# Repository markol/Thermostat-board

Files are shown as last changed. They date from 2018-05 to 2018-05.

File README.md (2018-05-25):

## Thermostat board on AVR atmega MCU
Digital temperature controler. Powered from mains network, can be build into DIY hardware or appiliances like fridge or oven. Easy to at home make, non precsion requiring THT desin with numeric 7-segment LED display, 2 control buttons, buzzer and rotary encoder for temp adjustment. Temperature is measured by one or two thermistors, all processing is done by atmega8 microcontroller or similar. Look also [here](http://github.com/markol/Thermostat-firmware) for firmware for this board. 

Design is made with KiCad, remember to add project footprint libraries (from *custom_fp.pretty* directory) when opening first time.

Currently project has only one master branch, other may appear when development proceed.

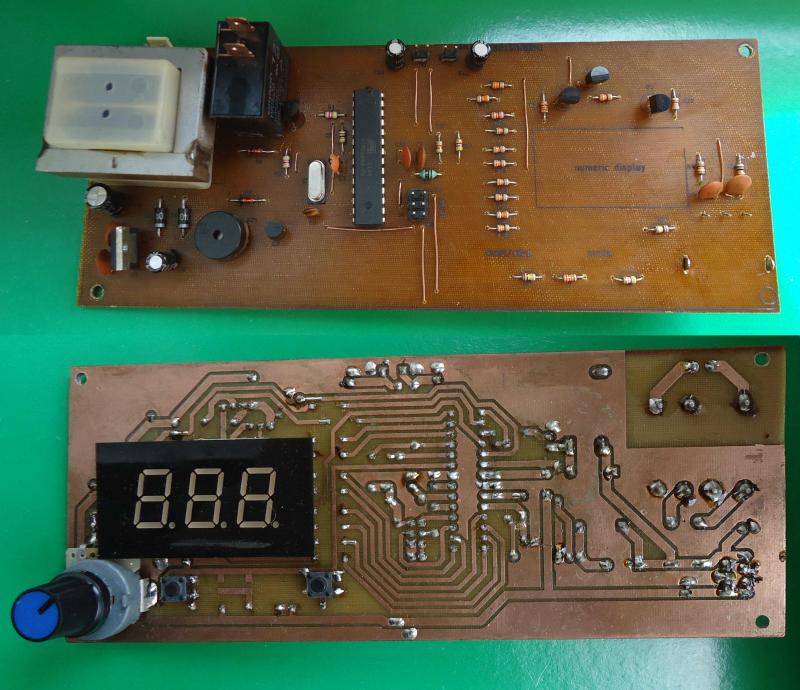
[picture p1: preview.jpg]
Prewiev


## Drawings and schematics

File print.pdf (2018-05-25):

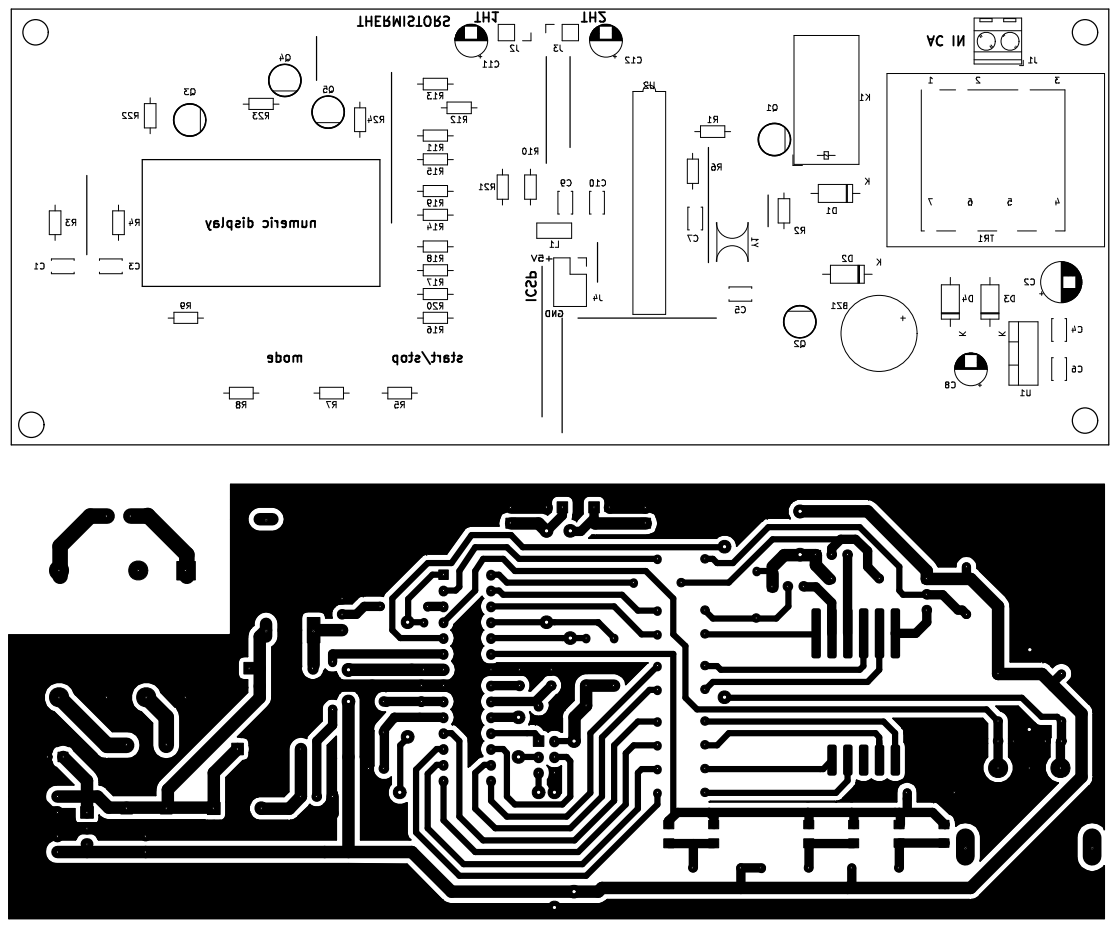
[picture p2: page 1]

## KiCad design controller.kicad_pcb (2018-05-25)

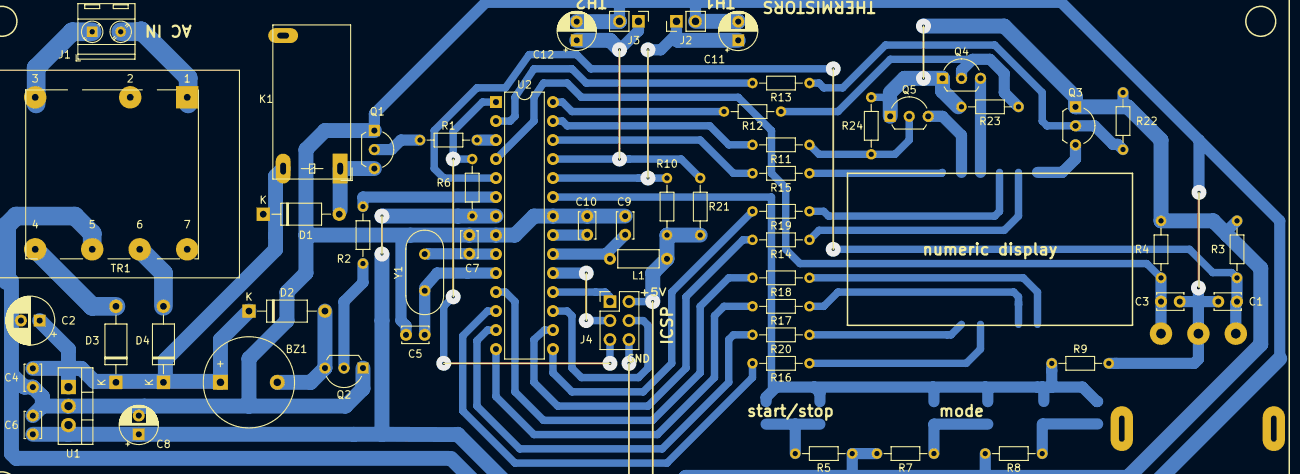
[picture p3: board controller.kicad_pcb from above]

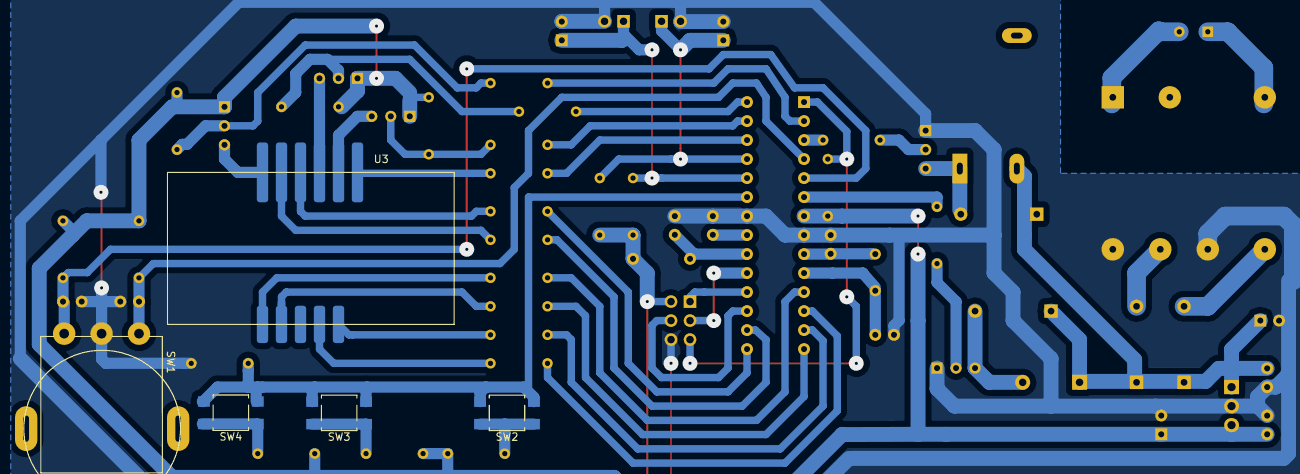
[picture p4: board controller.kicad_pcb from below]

Board: 2 copper layers, 61 parts (5 on the bottom side), 52 nets.

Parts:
BZ1: Buzzer; Buzzer_12x9.5RM7.6
C1, C3, C4, C6, C9, C10: 100nF; C_Disc_D3.4mm_W2.1mm_P2.50mm
C2: 100uF; CP_Radial_D6.3mm_P2.50mm
C5, C7: 22pF; C_Disc_D3.4mm_W2.1mm_P2.50mm
C8, C11, C12: 10uF; CP_Radial_D5.0mm_P2.50mm
D1, D2, D3, D4: D; D_A-405_P10.16mm_Horizontal
J1: AC_PWR; TerminalBlock_MetzConnect_Type086_RT03402HBLC_1x02_P3.81mm_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
J2: THERMISTOR1; PinHeader_1x02_P2.54mm_Vertical
J3: THERMISTOR2; PinHeader_1x02_P2.54mm_Vertical
J4: AVR_ICSP; PinHeader_2x03_P2.54mm_Vertical
K1: FRT5_separated; Relay_Omron
L1: L; L_Axial_L5.3mm_D2.2mm_P7.62mm_Horizontal_Vishay_IM-1
Q1, Q2: S9013; TO-92L_Inline_Wide
Q3, Q4, Q5: S9015; TO-92L_Inline_Wide
R1, R2: 4k7; R_Axial_DIN0204_L3.6mm_D1.6mm_P7.62mm_Horizontal
R3, R4, R5, R6: 10k; R_Axial_DIN0204_L3.6mm_D1.6mm_P7.62mm_Horizontal
R7: 22k; R_Axial_DIN0204_L3.6mm_D1.6mm_P7.62mm_Horizontal
R8: 47k; R_Axial_DIN0204_L3.6mm_D1.6mm_P7.62mm_Horizontal
R9: 100k; R_Axial_DIN0204_L3.6mm_D1.6mm_P7.62mm_Horizontal
R10, R21: 4.7k; R_Axial_DIN0204_L3.6mm_D1.6mm_P7.62mm_Horizontal
R11, R12, R13, R22, R23, R24: 3k3; R_Axial_DIN0204_L3.6mm_D1.6mm_P7.62mm_Horizontal
R14, R15, R16, R17, R18, R19, R20: 330; R_Axial_DIN0204_L3.6mm_D1.6mm_P7.62mm_Horizontal
SW1: Rotary_Encoder; Encoder_Vertical
SW2: START/STOP; SW_SPST_TL3305A
SW3: MODE; SW_SPST_TL3305A
SW4: SW_Push; SW_SPST_TL3305A
TR1: dmr-63; Transformer_7pin
U1: L7805; TO-220-3_Vertical
U2: ATmega8L-8PU; DIP-28_W7.62mm
U3: 3digit11pin
Y1: Crystal; Crystal_HC18-U_Vertical

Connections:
+5V: C6.1, C8.1, J4.2, L1.1, Q3.1, Q4.1, Q5.1, R3.2, R4.2, R5.2, R6.1, R7.2, R8.2, R10.1, R21.1, R22.2, R23.2, R24.2, U1.3, U2.7
/BUZZER: R2.2, U2.6
/DIGIT1: R13.2, U2.2
/DIGIT2: R12.2, U2.28
/DIGIT3: R11.2, U2.27
/DIGIT_A: R14.2, U2.16
/DIGIT_B: R15.2, U2.26
/DIGIT_C: R16.2, U2.12
/DIGIT_D: R17.2, U2.14
/DIGIT_E: R18.2, U2.11
/DIGIT_F: R19.2, U2.15
/DIGIT_G: R20.2, U2.13
/ENCODER_A: C3.1, R4.1, SW1.A, U2.4
/ENCODER_B: C1.1, R3.1, SW1.B, U2.5
/KEYS: R9.2, SW2.2, SW3.2, SW4.2, U2.23
/MISO: J4.1, U2.18
/MOSI: J4.4, U2.17
/RELAY: R1.2, U2.3
/RESET: J4.5, R6.2, U2.1
/SCK: J4.3, U2.19
/SENSOR1: C11.1, J2.1, R10.2, U2.24
/SENSOR2: C12.1, J3.1, R21.2, U2.25
GND: C1.2, C2.2, C3.2, C4.2, C5.2, C6.2, C7.2, C8.2, C9.2, C10.2, C11.2, C12.2, J2.2, J3.2, J4.6, Q1.1, Q2.1, R9.1, SW1.C, TR1.5, TR1.7, U1.2, U2.8, U2.22
unnamed: BZ1.2, D2.2, Q2.3
unnamed: C5.1, U2.10, Y1.1
unnamed: C7.1, U2.9, Y1.2
unnamed: C9.1, L1.2, U2.20
unnamed: C10.1, U2.21
unnamed: D1.2, K1.10, Q1.3
unnamed: D3.2, TR1.4
unnamed: D4.2, TR1.6
unnamed: J1.1, TR1.3
unnamed: J1.2, TR1.1
unnamed: Q1.2, R1.1
unnamed: Q2.2, R2.1
unnamed: Q3.2, R13.1, R22.1
unnamed: Q3.3, U3.1
unnamed: Q4.2, R12.1, R23.1
unnamed: Q4.3, U3.4
unnamed: Q5.2, R11.1, R24.1
unnamed: Q5.3, U3.5
unnamed: R5.1, SW2.1
unnamed: R7.1, SW3.1
unnamed: R8.1, SW4.1
unnamed: R14.1, U3.2
unnamed: R15.1, U3.6
unnamed: R16.1, U3.10
unnamed: R17.1, U3.8
unnamed: R18.1, U3.7
unnamed: R19.1, U3.3
unnamed: R20.1, U3.11
VDD: BZ1.1, C2.1, C4.1, D1.1, D2.1, D3.1, D4.1, K1.1, U1.1
